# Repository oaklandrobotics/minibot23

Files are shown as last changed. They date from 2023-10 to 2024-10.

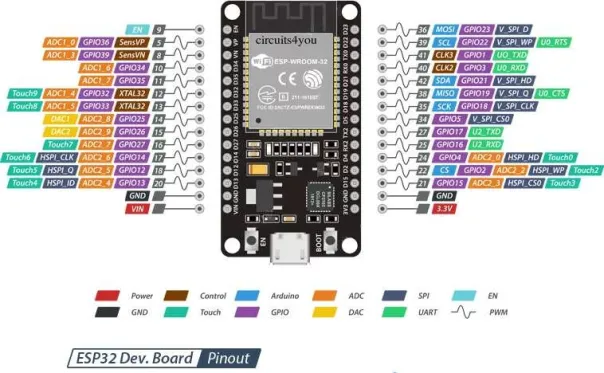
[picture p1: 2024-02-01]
PCB-Schematic/ESP32-Pinout.png

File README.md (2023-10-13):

# MiniBot 2023

Welcome to the MiniBot 2023 project! This repository serves as the documentation and codebase for our 2023 MiniBot project.

## Table of Contents

- [Introduction](#introduction)
- [Getting Started](#getting-started)
- [Documentation](#documentation)
- [Contributing](#contributing)

## Introduction

The MiniBot 2023 project is designed to provide club members with hands-on experience and training opportunities. This README will provide background information as well as instructions on how to get started. 

## Getting Started

To get started with the MiniBot 2023 project, follow these steps:

1. Clone this repository to your local machine:

   ```bash
   git clone https://github.com/oaklandrobotics/MiniBot-2023.git

## Documentation

W.I.P

## Contributing

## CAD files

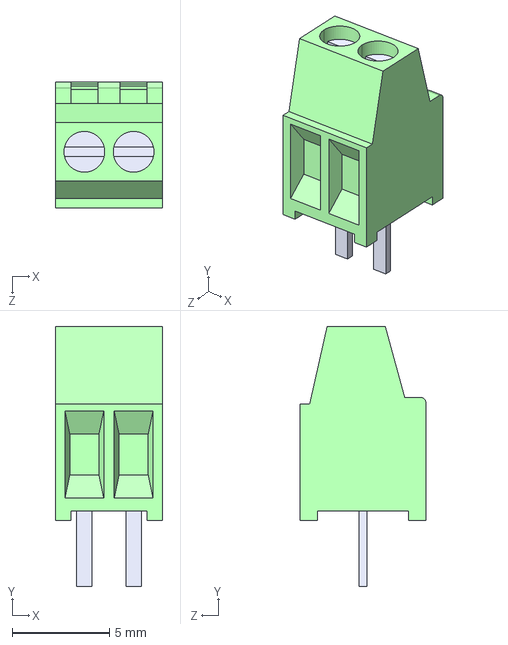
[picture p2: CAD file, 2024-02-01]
PCB-Schematic/minibot control/282834-2--3DModel-STEP-269445.STEP
5.54 x 13.4 x 6.50 mm

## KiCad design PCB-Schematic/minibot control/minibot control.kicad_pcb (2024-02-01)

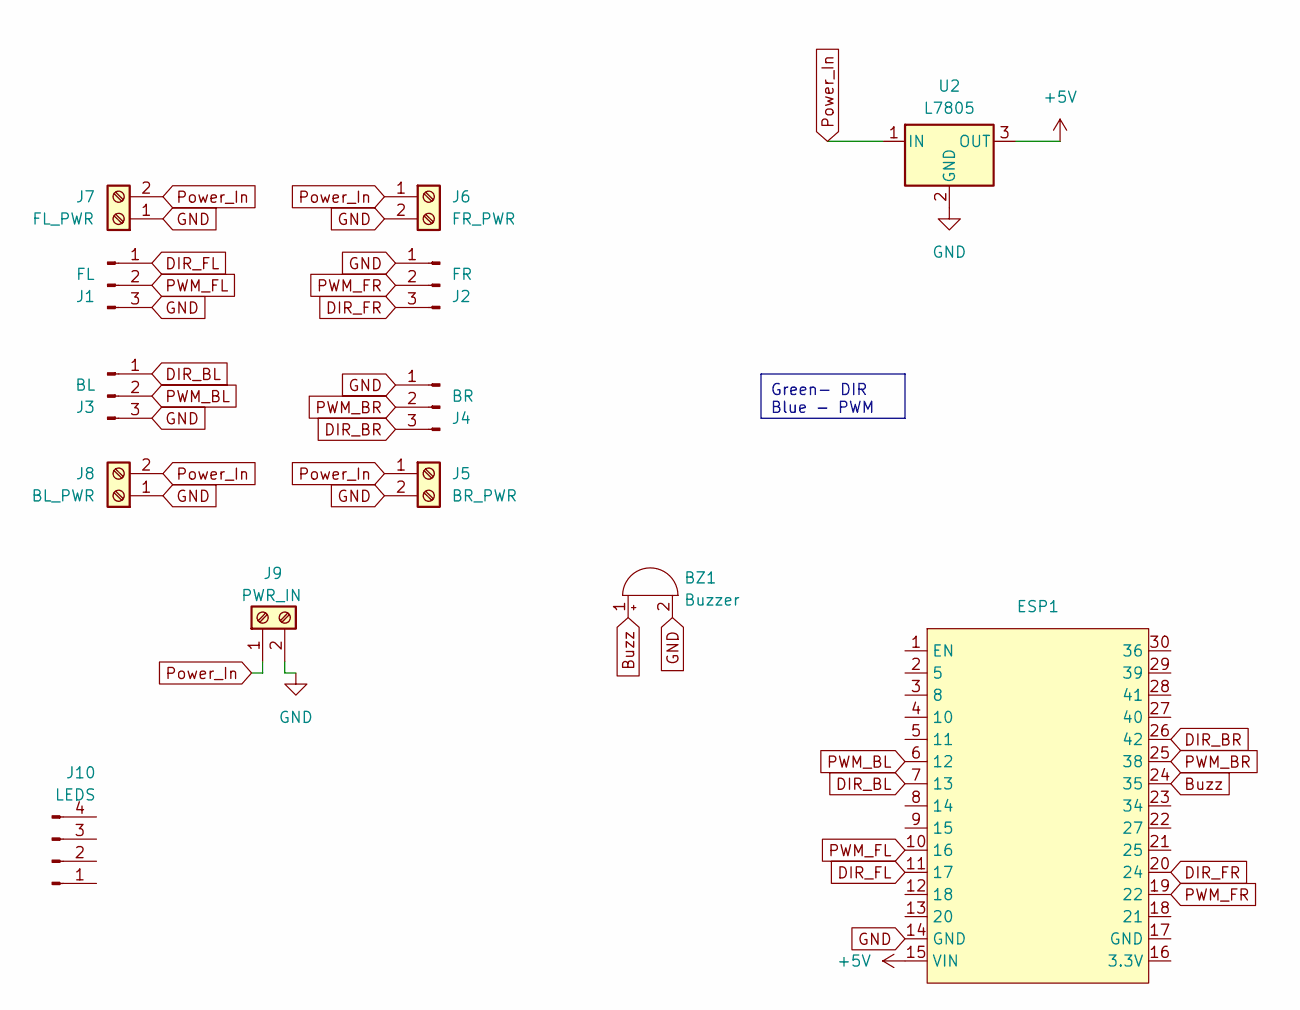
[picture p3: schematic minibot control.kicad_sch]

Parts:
BZ1: Buzzer; Buzzer_12x9.5RM7.6
ESP1: ESP-32
J1: FL; PinHeader_1x03_P2.54mm_Vertical
J2: FR; PinHeader_1x03_P2.54mm_Vertical
J3: BL; PinHeader_1x03_P2.54mm_Vertical
J4: BR; PinHeader_1x03_P2.54mm_Vertical
J5: BR_PWR; TerminalBlock_TE_282834-2_1x02_P2.54mm_Horizontal
J6: FR_PWR; TerminalBlock_TE_282834-2_1x02_P2.54mm_Horizontal
J7: FL_PWR; TerminalBlock_TE_282834-2_1x02_P2.54mm_Horizontal
J8: BL_PWR; TerminalBlock_TE_282834-2_1x02_P2.54mm_Horizontal
J9: PWR_IN; TerminalBlock_TE_282834-2_1x02_P2.54mm_Horizontal
J10: LEDS; PinHeader_1x04_P2.54mm_Vertical
U2: L7805; TO-3P-3_Vertical

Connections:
+5V: ESP1.15 (VIN), U2.3 (OUT)
Buzz: BZ1.1 (-), ESP1.24 (35)
DIR_BL: ESP1.7 (13), J3.1
DIR_BR: ESP1.26 (42), J4.3
DIR_FL: ESP1.11 (17), J1.1
DIR_FR: ESP1.20 (24), J2.3
GND: BZ1.2 (+), ESP1.14 (GND), J1.3, J2.1, J3.3, J4.1, J5.2, J6.2, J7.1, J8.1, J9.2, U2.2 (GND)
PWM_BL: ESP1.6 (12), J3.2
PWM_BR: ESP1.25 (38), J4.2
PWM_FL: ESP1.10 (16), J1.2
PWM_FR: ESP1.19 (22), J2.2
Power_In: J5.1, J6.1, J7.2, J8.2, J9.1, U2.1 (IN)

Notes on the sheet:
Green- DIR Blue - PWM

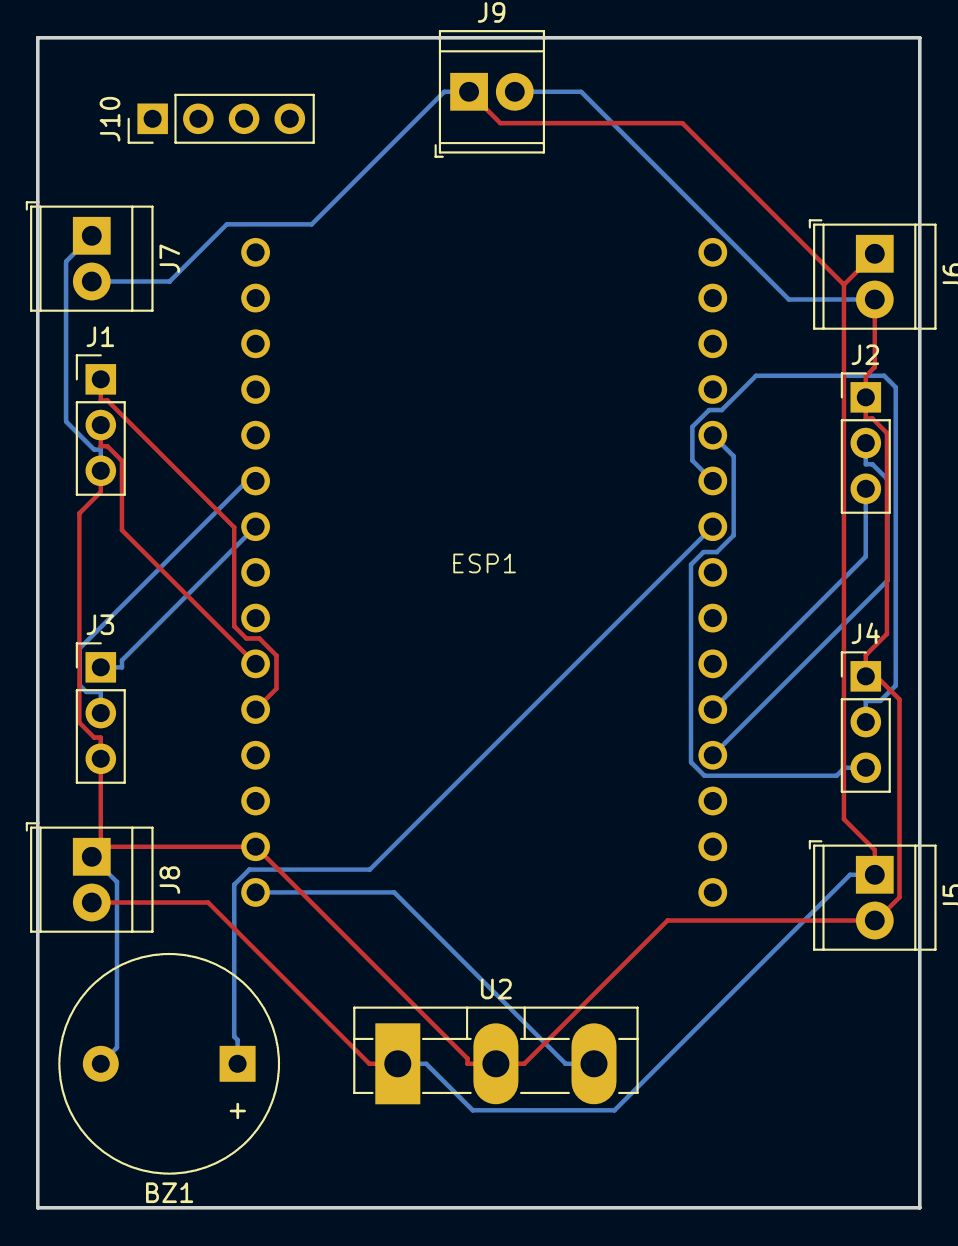
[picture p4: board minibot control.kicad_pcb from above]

Board: 2 copper layers, 49.0 x 65.0 mm, 13 parts (0 on the bottom side), 12 nets.

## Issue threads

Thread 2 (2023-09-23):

ESP-32 Controller Switching

AndrewMcGhee, 2023-09-23:
Start on the ESP32 daughterboard code to allow for wireless Bluetooth communication with multiple devices.

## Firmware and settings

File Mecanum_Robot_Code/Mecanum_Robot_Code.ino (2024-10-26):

#include <PS4Controller.h>

// Motor PWM Pins
const int motorFL = 32; // Front-left motor
const int motorFR = 19; // Front-right motor
const int motorBL = 14; //2 // Back-left motor
const int motorBR = 2; //14 // Back-right motor

// Direction control pins
const int dirFL = 33; // Front-left motor 
const int dirFR = 21; // Front-right motor 
const int dirBL = 12;  //4// Back-left motor 
const int dirBR = 4; //12 // Back-right motor

const int deadband = 9;

// Setting Speed and Direction
void setMotorSpeedAndDirection(int motorPin, int dirPin, int speed, int direction) {
  // Constrains to a Valid Speed
  speed = constrain(speed, 0, 255);
  
  // Sets the Direction
  digitalWrite(dirPin, direction);
  
  // Sets the Speed
  analogWrite(motorPin, speed);
}

 //  Drive Function
void mecanumDrive(int x, int y, int rotation) {
  int FL_speed = y + x + rotation;
  int FR_speed = y - x - rotation;
  int BL_speed = y - x + rotation;
  int BR_speed = y + x - rotation;
  
  // Keeps Speed within Valid Range
  int maxSpeed = max(max(abs(FL_speed), abs(FR_speed)), max(abs(BL_speed), abs(BR_speed)));
  if (maxSpeed > 255) {
    FL_speed = map(FL_speed, -maxSpeed, maxSpeed, -255, 255);
    FR_speed = map(FR_speed, -maxSpeed, maxSpeed, -255, 255);
    BL_speed = map(BL_speed, -maxSpeed, maxSpeed, -255, 255);
    BR_speed = map(BR_speed, -maxSpeed, maxSpeed, -255, 255);
  }
  
  // Sets Motor Speeds and Directions
  setMotorSpeedAndDirection(motorFL, dirFL, abs(FL_speed), FL_speed >= 0 ? HIGH : LOW);
  setMotorSpeedAndDirection(motorFR, dirFR, abs(FR_speed), FR_speed >= 0 ? HIGH : LOW);
  setMotorSpeedAndDirection(motorBL, dirBL, abs(BL_speed), BL_speed >= 0 ? HIGH : LOW);
  setMotorSpeedAndDirection(motorBR, dirBR, abs(BR_speed), BR_speed >= 0 ? HIGH : LOW);
}

void twoWheelDrive(int LSpeed, int RSpeed) {
  LSpeed = map(LSpeed, -127, 127, -255, 255);
  RSpeed = map(RSpeed, -127, 127, -255, 255);

  setMotorSpeedAndDirection(motorFL, dirFL, abs(LSpeed), LSpeed >= 0 ? HIGH : LOW);
  setMotorSpeedAndDirection(motorFR, dirFR, abs(RSpeed), RSpeed >= 0 ? HIGH : LOW);
  setMotorSpeedAndDirection(motorBL, dirBL, abs(LSpeed), LSpeed >= 0 ? HIGH : LOW);
  setMotorSpeedAndDirection(motorBR, dirBR, abs(RSpeed), RSpeed >= 0 ? HIGH : LOW);
}

void tankDrive(int LStick, int RStick) {
  LStick = map(LStick, -127, 127, -255, 255);
  RStick = map(RStick, -127, 127, -255, 255);
  int leftWheelTurn = -RStick;
  int rightWheelTurn = RStick;
  int LSpeed = LStick + leftWheelTurn;
  int RSpeed = LStick + rightWheelTurn;
  if (abs(LSpeed) > 255)
    if (LSpeed < 0)
      LSpeed = -255;
    else
      LSpeed = 255;
  if (abs(RSpeed) > 255)
    if (RSpeed < 0)
      RSpeed = -255;
    else
      RSpeed = 255;

  setMotorSpeedAndDirection(motorFL, dirFL, abs(LSpeed), LSpeed >= 0 ? HIGH : LOW);
  setMotorSpeedAndDirection(motorFR, dirFR, abs(RSpeed), RSpeed >= 0 ? HIGH : LOW);
  setMotorSpeedAndDirection(motorBL, dirBL, abs(LSpeed), LSpeed >= 0 ? HIGH : LOW);
  setMotorSpeedAndDirection(motorBR, dirBR, abs(RSpeed), RSpeed >= 0 ? HIGH : LOW);
}

void oneStickDrive(int X, int Y) {
  X = map(X, -127, 127, -255, 255);
  Y = map(Y, -127, 127, -255, 255);
  int leftWheelTurn = -X;
  int rightWheelTurn = X;
  int LSpeed = Y + leftWheelTurn;
  int RSpeed = Y + rightWheelTurn;
  if (abs(LSpeed) > 255)
    if (LSpeed < 0)
      LSpeed = -255;
    else
      LSpeed = 255;
  if (abs(RSpeed) > 255)
    if (RSpeed < 0)
      RSpeed = -255;
    else
      RSpeed = 255;

  setMotorSpeedAndDirection(motorFL, dirFL, abs(LSpeed), LSpeed >= 0 ? HIGH : LOW);
  setMotorSpeedAndDirection(motorFR, dirFR, abs(RSpeed), RSpeed >= 0 ? HIGH : LOW);
  setMotorSpeedAndDirection(motorBL, dirBL, abs(LSpeed), LSpeed >= 0 ? HIGH : LOW);
  setMotorSpeedAndDirection(motorBR, dirBR, abs(RSpeed), RSpeed >= 0 ? HIGH : LOW);  
}

void setup() {
  PS4.begin("ac:89:95:6b:70:e4");
  Serial.begin(115200);
  // Initialize Direction Control Pins as OUTPUT
  pinMode(dirFL, OUTPUT);
  pinMode(dirFR, OUTPUT);
  pinMode(dirBL, OUTPUT);
  pinMode(dirBR, OUTPUT);
  
  // Initialize Motor Control Pins as OUTPUT
  pinMode(motorFL, OUTPUT);
  pinMode(motorFR, OUTPUT);
  pinMode(motorBL, OUTPUT);
  pinMode(motorBR, OUTPUT);
  Serial.println("Booting");
}

void loop() {

// Put Movement Directions Here 
// Example:
  //delay(1000);
  //MoveRight(255);
  int leftStick = PS4.LStickY();
  int leftStickX = PS4.LStickX();
  int rightStick = PS4.RStickY();
  int rightStickX = PS4.RStickX();
  if (abs(leftStick) < deadband)
    leftStick = 0;
  if (abs(leftStickX) < deadband)
    leftStickX = 0;
  if (abs(rightStick) < deadband)
    rightStick = 0;
  if (abs(rightStickX) < deadband)
    rightStickX = 0;

  //twoWheelDrive(leftStick, rightStick);
  //tankDrive(leftStick, rightStickX);
  //oneStickDrive(leftStickX, leftStick);
  // For mecanum drive
  leftStickX = map(leftStickX, -127, 127, -255, 255);
  leftStick = map(leftStick, -127, 127, -255, 255);
  rightStickX = map(rightStickX, -127, 127, -255, 255);
  mecanumDrive(leftStickX, leftStick, rightStickX);
  //delay(1000);
// This moves forward full speed for 1 second
  //Serial.println("Driving");
  Serial.printf("Left X: %d\n", PS4.LStickX());
  Serial.printf("Left Y: %d\n",PS4.LStickY());
  Serial.printf("Right X: %d\n",PS4.RStickX());
  Serial.printf("Right Y: %d\n",PS4.RStickY());
}

void MoveForward(int Speed) {
  mecanumDrive(0, Speed, 0);
}

void MoveBackward(int Speed) {
  mecanumDrive(0, -Speed, 0);
}

void MoveRight(int Speed) {
  mecanumDrive(-Speed, 0, 0);
}

void MoveLeft(int Speed) {
  mecanumDrive(Speed, 0, 0);
}

void RotateLeft(int Speed) {
  mecanumDrive(0, 0, -Speed);
}

void RotateRight(int Speed) {
  mecanumDrive(0,0,Speed);
}

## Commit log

2023-10-14 Update pinouts for current layout
2024-02-01 I forgor to upload
    [282834-2--3DModel-STEP-269445.STEP, minibot control.kicad_pcb, minibot control.kicad_sch]
2024-09-27 Fix the pins, add delay
    Thanks to George for his energy.
    [Mecanum_Robot_Code.ino]
2024-10-25 Fix back motor pins, add PS4 support
    [Mecanum_Robot_Code.ino]
2024-10-26 Fix deadband again and speed clamping
    [Mecanum_Robot_Code.ino]
